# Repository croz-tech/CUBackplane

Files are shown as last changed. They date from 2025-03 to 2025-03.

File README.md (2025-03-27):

# Control Universal 4-Slot DIN41612 Backplane
***Note: Early preview only... at this time this board has not been fabricated/tested***

A 4 slot DIN 41612 backplane for use with the EuroBEEB and compatible cards

PCB top side view PCB solder side view

- Designed in KiCAD, in addition to giving 4x DIN connectors on a 1" (5HP spacing) allowing mounting in a 24HP enclosure with 2HP blanking plates at either end.
- Board has pads for power supply inputs (actually only +5V and GND are needed for a standard EuroBEEB) and test points for access to all Data, Control and Address lines.  These TPs are labelled on the under/back side for easy access when this is mounted in a rack.  The TPs are on a 0.1" pitch, so headers can be used if desired.
- Board is <100x100mm so should be low-cost fabrication.

Note that this isn't strictly a 'backplane' in the DIN enclosure sense.  Rather than mounting the PCB to 'backplane' fixtures in an enclosure, the PCB should simply be soldered across the row of vertical DIN female connectors and then the connectors mounted to specific connector mounting rails.  Please take this into consideration if ordering enclosure parts from Verotec or your preferred enclosure supplier.

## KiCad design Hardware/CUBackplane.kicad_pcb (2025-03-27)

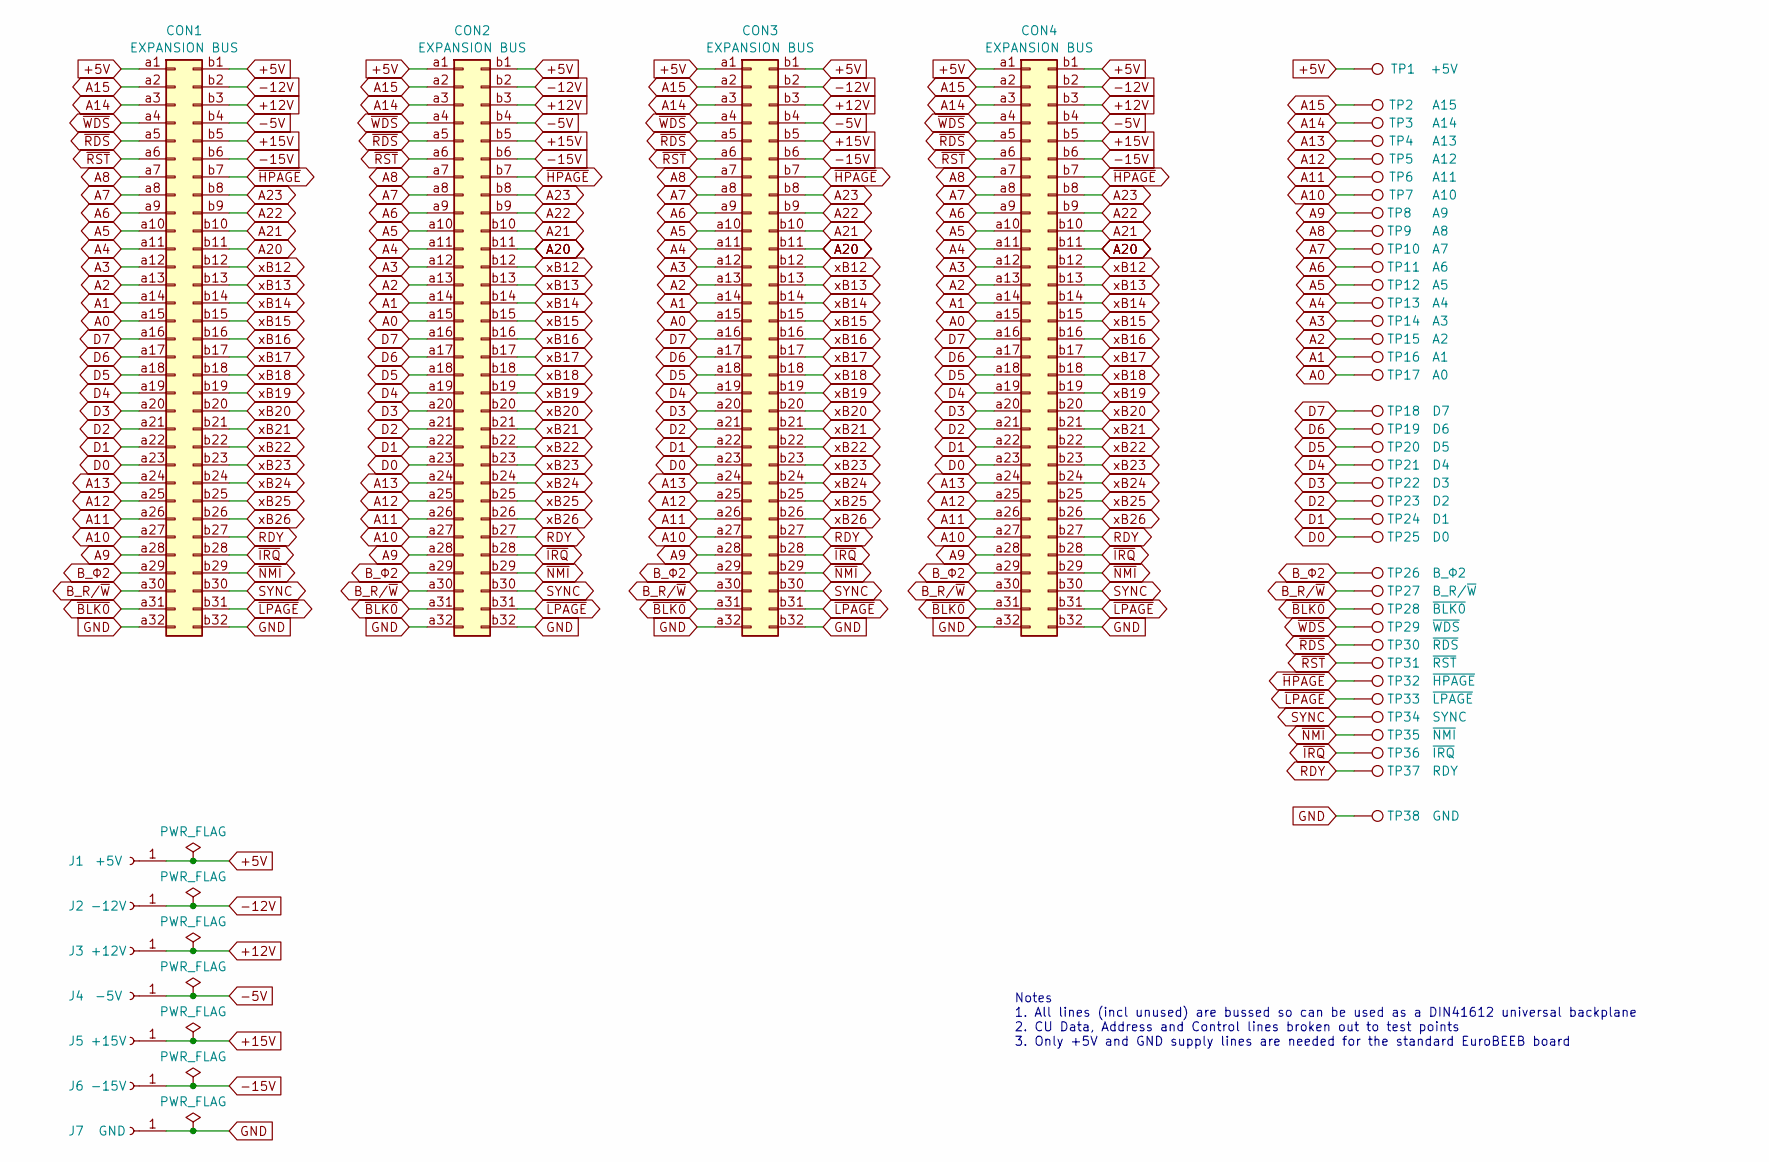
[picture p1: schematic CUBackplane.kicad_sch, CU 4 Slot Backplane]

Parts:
CON1, CON2, CON3, CON4: EXPANSION BUS; DIN41612_B_2x32_Female_Vertical_THT
J1: +5V; TestPoint_THTPad_D3.0mm_Drill1.5mm
J2: -12V; TestPoint_THTPad_D2.0mm_Drill1.0mm
J3: +12V; TestPoint_THTPad_D2.0mm_Drill1.0mm
J4: -5V; TestPoint_THTPad_D2.0mm_Drill1.0mm
J5: +15V; TestPoint_THTPad_D2.0mm_Drill1.0mm
J6: -15V; TestPoint_THTPad_D2.0mm_Drill1.0mm
J7: GND; TestPoint_THTPad_D3.0mm_Drill1.5mm
TP1: +5V; TestPoint_THTPad_D1.5mm_Drill0.7mm
TP2: A15; TestPoint_THTPad_D1.5mm_Drill0.7mm
TP3: A14; TestPoint_THTPad_D1.5mm_Drill0.7mm
TP4: A13; TestPoint_THTPad_D1.5mm_Drill0.7mm
TP5: A12; TestPoint_THTPad_D1.5mm_Drill0.7mm
TP6: A11; TestPoint_THTPad_D1.5mm_Drill0.7mm
TP7: A10; TestPoint_THTPad_D1.5mm_Drill0.7mm
TP8: A9; TestPoint_THTPad_D1.5mm_Drill0.7mm
TP9: A8; TestPoint_THTPad_D1.5mm_Drill0.7mm
TP10: A7; TestPoint_THTPad_D1.5mm_Drill0.7mm
TP11: A6; TestPoint_THTPad_D1.5mm_Drill0.7mm
TP12: A5; TestPoint_THTPad_D1.5mm_Drill0.7mm
TP13: A4; TestPoint_THTPad_D1.5mm_Drill0.7mm
TP14: A3; TestPoint_THTPad_D1.5mm_Drill0.7mm
TP15: A2; TestPoint_THTPad_D1.5mm_Drill0.7mm
TP16: A1; TestPoint_THTPad_D1.5mm_Drill0.7mm
TP17: A0; TestPoint_THTPad_D1.5mm_Drill0.7mm
TP18: D7; TestPoint_THTPad_D1.5mm_Drill0.7mm
TP19: D6; TestPoint_THTPad_D1.5mm_Drill0.7mm
TP20: D5; TestPoint_THTPad_D1.5mm_Drill0.7mm
TP21: D4; TestPoint_THTPad_D1.5mm_Drill0.7mm
TP22: D3; TestPoint_THTPad_D1.5mm_Drill0.7mm
TP23: D2; TestPoint_THTPad_D1.5mm_Drill0.7mm
TP24: D1; TestPoint_THTPad_D1.5mm_Drill0.7mm
TP25: D0; TestPoint_THTPad_D1.5mm_Drill0.7mm
TP26: B_Φ2; TestPoint_THTPad_D1.5mm_Drill0.7mm
TP27: B_R/~{W}; TestPoint_THTPad_D1.5mm_Drill0.7mm
TP28: ~{BLK0}; TestPoint_THTPad_D1.5mm_Drill0.7mm
TP29: ~{WDS}; TestPoint_THTPad_D1.5mm_Drill0.7mm
TP30: ~{RDS}; TestPoint_THTPad_D1.5mm_Drill0.7mm
TP31: ~{RST}; TestPoint_THTPad_D1.5mm_Drill0.7mm
TP32: ~{HPAGE}; TestPoint_THTPad_D1.5mm_Drill0.7mm
TP33: ~{LPAGE}; TestPoint_THTPad_D1.5mm_Drill0.7mm
TP34: SYNC; TestPoint_THTPad_D1.5mm_Drill0.7mm
TP35: ~{NMI}; TestPoint_THTPad_D1.5mm_Drill0.7mm
TP36: ~{IRQ}; TestPoint_THTPad_D1.5mm_Drill0.7mm
TP37: RDY; TestPoint_THTPad_D1.5mm_Drill0.7mm
TP38: GND; TestPoint_THTPad_D1.5mm_Drill0.7mm

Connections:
+5V: CON1.a1, CON1.b1, CON2.a1, CON2.b1, CON3.a1, CON3.b1, CON4.a1, CON4.b1, J1.1, TP1.1
+12V: CON1.b3, CON2.b3, CON3.b3, CON4.b3, J3.1
+15V: CON1.b5, CON2.b5, CON3.b5, CON4.b5, J5.1
-5V: CON1.b4, CON2.b4, CON3.b4, CON4.b4, J4.1
-12V: CON1.b2, CON2.b2, CON3.b2, CON4.b2, J2.1
-15V: CON1.b6, CON2.b6, CON3.b6, CON4.b6, J6.1
A0: CON1.a15, CON2.a15, CON3.a15, CON4.a15, TP17.1
A1: CON1.a14, CON2.a14, CON3.a14, CON4.a14, TP16.1
A2: CON1.a13, CON2.a13, CON3.a13, CON4.a13, TP15.1
A3: CON1.a12, CON2.a12, CON3.a12, CON4.a12, TP14.1
A4: CON1.a11, CON2.a11, CON3.a11, CON4.a11, TP13.1
A5: CON1.a10, CON2.a10, CON3.a10, CON4.a10, TP12.1
A6: CON1.a9, CON2.a9, CON3.a9, CON4.a9, TP11.1
A7: CON1.a8, CON2.a8, CON3.a8, CON4.a8, TP10.1
A8: CON1.a7, CON2.a7, CON3.a7, CON4.a7, TP9.1
A9: CON1.a28, CON2.a28, CON3.a28, CON4.a28, TP8.1
A10: CON1.a27, CON2.a27, CON3.a27, CON4.a27, TP7.1
A11: CON1.a26, CON2.a26, CON3.a26, CON4.a26, TP6.1
A12: CON1.a25, CON2.a25, CON3.a25, CON4.a25, TP5.1
A13: CON1.a24, CON2.a24, CON3.a24, CON4.a24, TP4.1
A14: CON1.a3, CON2.a3, CON3.a3, CON4.a3, TP3.1
A15: CON1.a2, CON2.a2, CON3.a2, CON4.a2, TP2.1
A20: CON1.b11, CON2.b11, CON3.b11, CON4.b11
A21: CON1.b10, CON2.b10, CON3.b10, CON4.b10
A22: CON1.b9, CON2.b9, CON3.b9, CON4.b9
A23: CON1.b8, CON2.b8, CON3.b8, CON4.b8
B_R/~W: CON1.a30, CON2.a30, CON3.a30, CON4.a30, TP27.1
B_Φ2: CON1.a29, CON2.a29, CON3.a29, CON4.a29, TP26.1
D0: CON1.a23, CON2.a23, CON3.a23, CON4.a23, TP25.1
D1: CON1.a22, CON2.a22, CON3.a22, CON4.a22, TP24.1
D2: CON1.a21, CON2.a21, CON3.a21, CON4.a21, TP23.1
D3: CON1.a20, CON2.a20, CON3.a20, CON4.a20, TP22.1
D4: CON1.a19, CON2.a19, CON3.a19, CON4.a19, TP21.1
D5: CON1.a18, CON2.a18, CON3.a18, CON4.a18, TP20.1
D6: CON1.a17, CON2.a17, CON3.a17, CON4.a17, TP19.1
D7: CON1.a16, CON2.a16, CON3.a16, CON4.a16, TP18.1
GND: CON1.a32, CON1.b32, CON2.a32, CON2.b32, CON3.a32, CON3.b32, CON4.a32, CON4.b32, J7.1, TP38.1
RDY: CON1.b27, CON2.b27, CON3.b27, CON4.b27, TP37.1
SYNC: CON1.b30, CON2.b30, CON3.b30, CON4.b30, TP34.1
xB12: CON1.b12, CON2.b12, CON3.b12, CON4.b12
xB13: CON1.b13, CON2.b13, CON3.b13, CON4.b13
xB14: CON1.b14, CON2.b14, CON3.b14, CON4.b14
xB15: CON1.b15, CON2.b15, CON3.b15, CON4.b15
xB16: CON1.b16, CON2.b16, CON3.b16, CON4.b16
xB17: CON1.b17, CON2.b17, CON3.b17, CON4.b17
xB18: CON1.b18, CON2.b18, CON3.b18, CON4.b18
xB19: CON1.b19, CON2.b19, CON3.b19, CON4.b19
xB20: CON1.b20, CON2.b20, CON3.b20, CON4.b20
xB21: CON1.b21, CON2.b21, CON3.b21, CON4.b21
xB22: CON1.b22, CON2.b22, CON3.b22, CON4.b22
xB23: CON1.b23, CON2.b23, CON3.b23, CON4.b23
xB24: CON1.b24, CON2.b24, CON3.b24, CON4.b24
xB25: CON1.b25, CON2.b25, CON3.b25, CON4.b25
xB26: CON1.b26, CON2.b26, CON3.b26, CON4.b26
~BLK0: CON1.a31, CON2.a31, CON3.a31, CON4.a31, TP28.1
~HPAGE: CON1.b7, CON2.b7, CON3.b7, CON4.b7, TP32.1
~IRQ: CON1.b28, CON2.b28, CON3.b28, CON4.b28, TP36.1
~LPAGE: CON1.b31, CON2.b31, CON3.b31, CON4.b31, TP33.1
~NMI: CON1.b29, CON2.b29, CON3.b29, CON4.b29, TP35.1
~RDS: CON1.a5, CON2.a5, CON3.a5, CON4.a5, TP30.1
~RST: CON1.a6, CON2.a6, CON3.a6, CON4.a6, TP31.1
~WDS: CON1.a4, CON2.a4, CON3.a4, CON4.a4, TP29.1

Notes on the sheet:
Notes 1. All lines (incl unused) are bussed so can be used as a DIN41612 universal backplane 2. CU Data, Address and Control lines broken out to test points 3. Only +5V and GND supply lines are needed for the standard EuroBEEB board

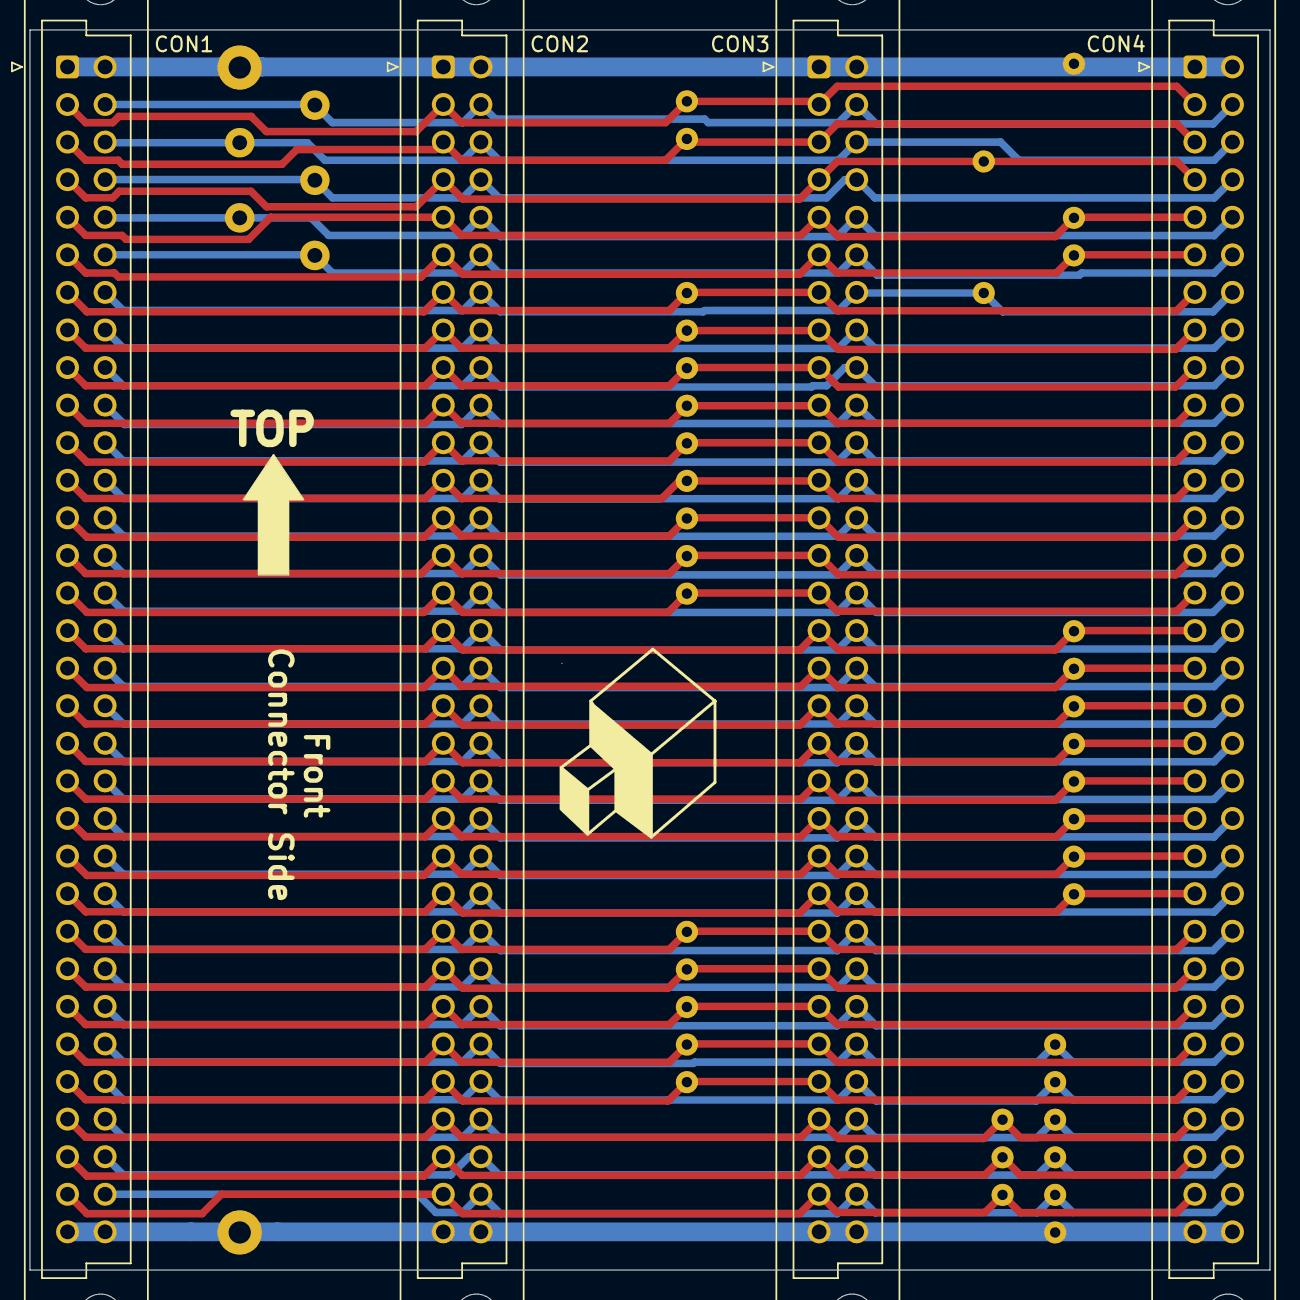
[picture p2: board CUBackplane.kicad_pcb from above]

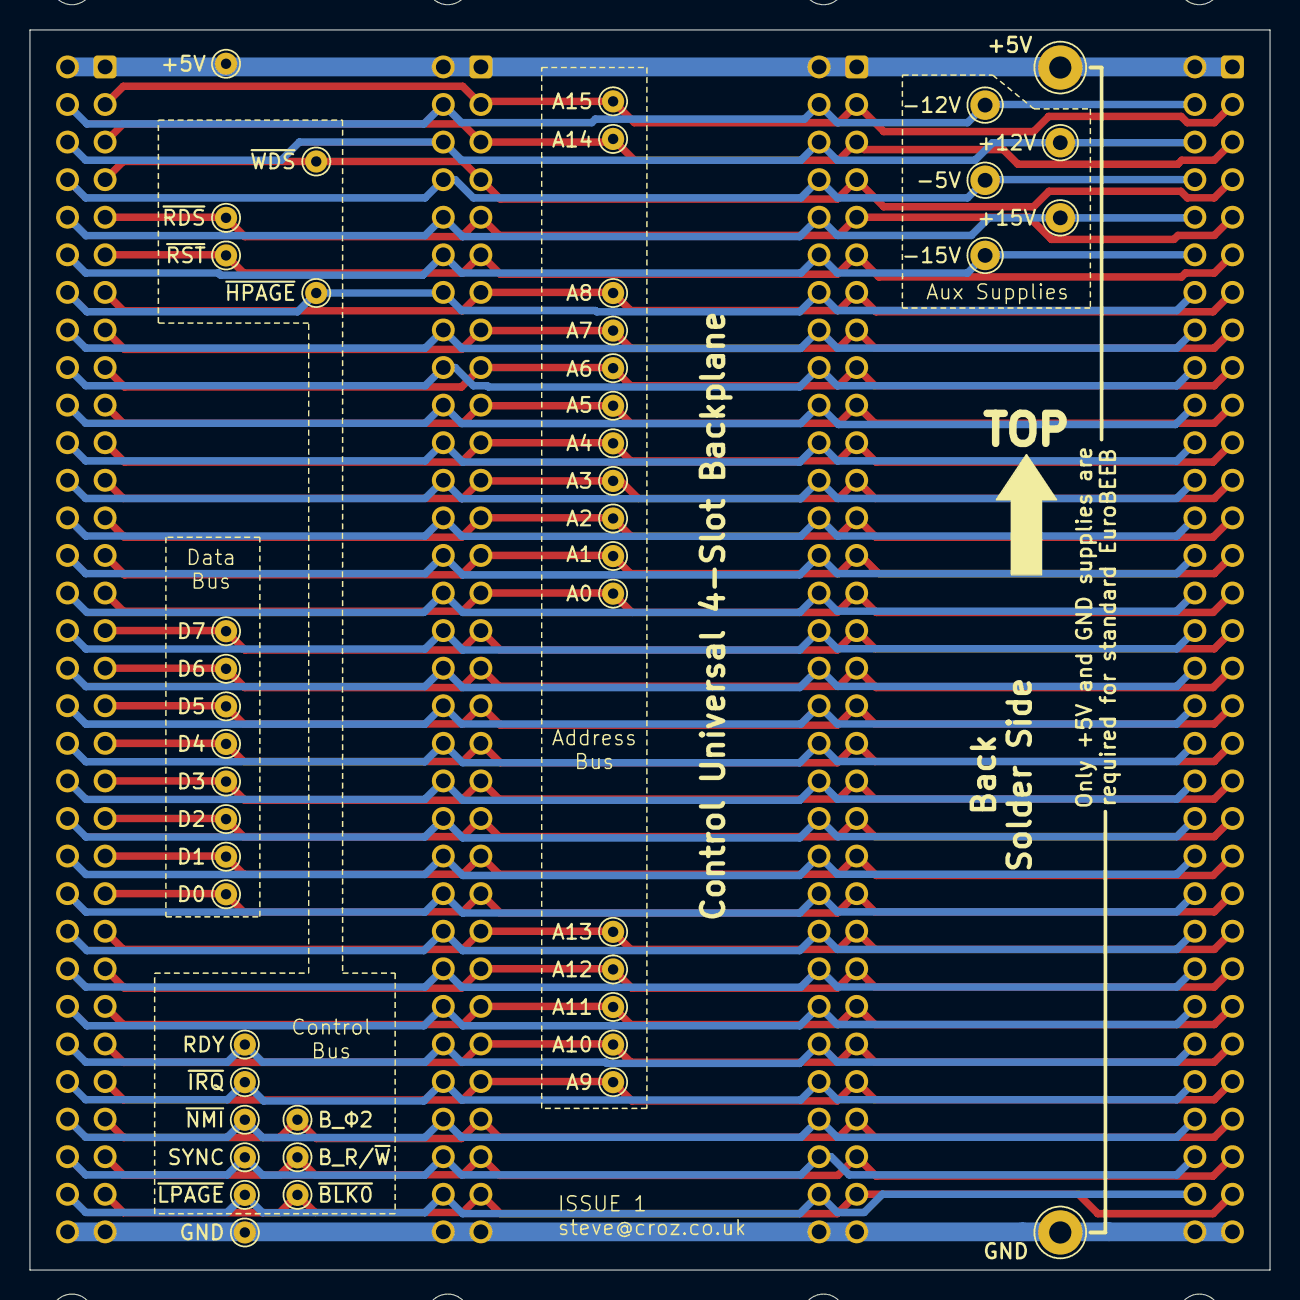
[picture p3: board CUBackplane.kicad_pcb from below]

Board: 2 copper layers, 83.8 x 83.8 mm, 49 parts (45 on the bottom side), 62 nets.

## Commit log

2025-03-27 Initial version
    [CUBackplane.kicad_pcb, CUBackplane.kicad_sch]
2025-03-27 Corrected board outline to 3.3x3.3
    [CUBackplane.kicad_pcb]
2025-03-27 Moved connector references
    [CUBackplane.kicad_pcb, CUBackplane.kicad_sch]
